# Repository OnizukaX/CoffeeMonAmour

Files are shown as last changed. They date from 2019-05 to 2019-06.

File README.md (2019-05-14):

# CoffeeMonAmour

For aficionados sharing coffee machines e.g. in a company using RFID authentication badges.

A good office day usually starts with a cup of your favorite beverage. You go to the nearest coffee machine, select your favorite beverage and look at it slowly filling up your favorite mug. Then, possibly, you will start looking for your name on a sheet of paper and put a tick under it, you will later have to pay your dues. Then as the day goes, you run from one meeting to another one, and frequently stop by other coffee machines ran by other coffee aficionados. The process repeats itself again and again.
Keeping finances up to date slowly becomes complicated and unpaid paper sheets soon become your new paperwall.

Without any hardware modification, you can add extra devices that track user accross all the coffee machines.

## DataFlow
NodeMCU + RFID reader + MIFARE Classic card --(WiFi)--> Google Script --> Google Spreadsheet --> Google Script --(WiFi)--> NodeMCU

## Hardware
* 1x NodeMCU ESP-WROOM-32 [https://cdn.shopify.com/s/files/1/1509/1638/files/ESP_-_32_NodeMCU_Developmentboard_Datenblatt_a3bf98d8-6a53-4d26-8f1c-c61b1c82af39.pdf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, https://www.espressif.com/sites/default/files/documentation/esp32-wroom-32_datasheet_en.pdf]
* 1x RFID-RC522 [
https://cdn.shopify.com/s/files/1/1509/1638/files/RFID_RC522_Set_mit_Reader_Chip_und_Card_13_56MHz_Datenblatt.pdf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, https://www.nxp.com/docs/en/data-sheet/MFRC522.pdf]
* 1x MIFARE Classic card [https://www.nxp.com/docs/en/data-sheet/MF1S50YYX_V1.pdf]
* 3x LEDs (red, green and blue)
* 1x OLED display with SSD1306 driver (e.g. GM009605)
* 1x micro-USB cable (check your wires if you get a Brown Out Reset (BOR))
* 1x screw for the capacitive touch button (combined with a ESP32 capacity touch pad)

## Libraries
* SPI [ESP32]
* WiFiClientSecure [ESP32]
* MFRC522 [https://github.com/miguelbalboa/rfid]
* SSD1306 [https://github.com/ThingPulse/esp8266-oled-ssd1306]

## Credits for pulling things together
* "ESP32 and RFID-RC522 module example" [http://www.esp32learning.com/code/esp32-and-rfid-rc522-module-example.php]
* "ESP32 und Google Tabellen (Sheets)" [http://esp32-server.de/google-sheets/]

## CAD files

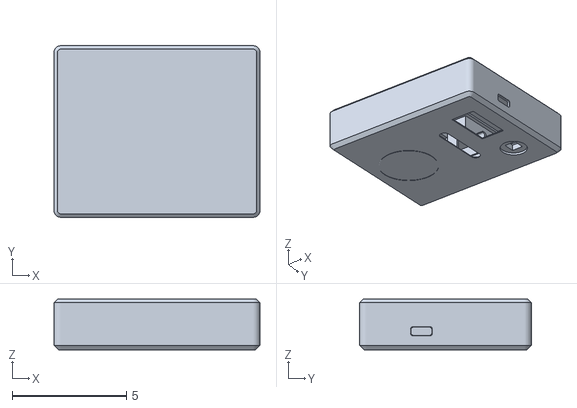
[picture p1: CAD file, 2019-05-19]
CoffeeMonAmour_Case_Group.stl
9.00 x 7.50 x 2.22

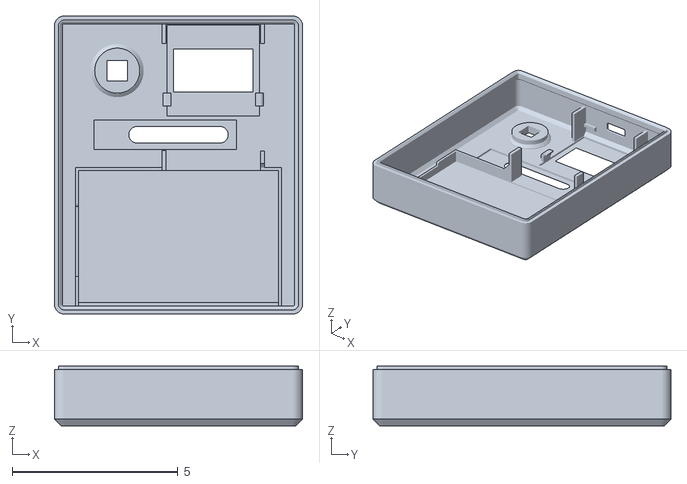
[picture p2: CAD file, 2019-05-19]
CoffeeMonAmour_Case_Top.stl
7.50 x 9.00 x 1.80

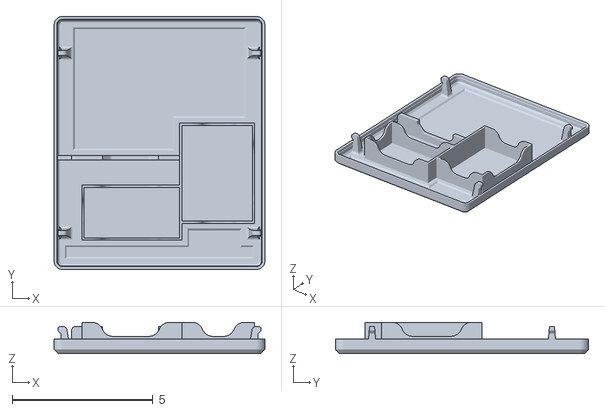
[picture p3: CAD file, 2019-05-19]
CoffeeMonAmour_Case_Bottom.stl
7.50 x 9.00 x 1.12

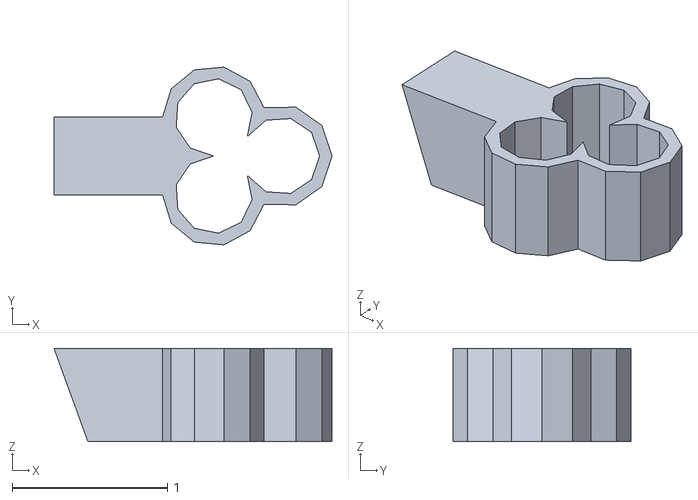
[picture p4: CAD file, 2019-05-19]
CoffeeMonAmour_Case_Led_Holder.stl
1.79 x 1.15 x 0.6

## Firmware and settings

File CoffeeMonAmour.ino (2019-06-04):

#include "Remote.hpp"
#include "Reader.hpp"
#include "Hmi.hpp"

/*
  Default pins layout.
  +---------+-------+------+-----+--------+
  | NodeMCU | RC522 | OLED | LED | Button |
  +---------+-------+------+-----+--------|
  | GPIO-21 |  SDA  |      |     |        |
  | GPIO-18 |  SCK  |      |     |        |
  | GPIO-23 |  MOSI |      |     |        |
  | GPIO-19 |  MISO |      |     |        |
  | GPIO-22 |  RST  |      |     |        |
  | GPIO-5  |       | SCK  |     |        |
  | GPIO-4  |       | SDA  |     |        |
  | GPIO-33 |       |      |  R  |        |
  | GPIO-26 |       |      |  G  |        |
  | GPIO-25 |       |      |  B  |        |
  | GPIO-27 |       |      |     |  Touch |
  +---------+-------+------+-----+--------+
  The RC522 and the OLED display are powered with 3.3V.
  The LEDs@20Ma are powered with 3.3V and each of them is in series with a 100Ohm resistors.
*/

/* Determine on which Core Arduino is running. */
#if CONFIG_FREERTOS_UNICORE
# define ARDUINO_RUNNING_CORE 0
#else
# define ARDUINO_RUNNING_CORE 1
#endif

#define GOOGLE_KEY "XXX"

#define DATA_SUCCESS_BLINK_NB (3U)
#define DATA_SUCCESS_BLINK_PERIOD_MS (600U)
#define DATA_ERROR_DISPLAY_MS (2000U)

/* Print debug data. */
#define DEBUG_ON (false)

#define DEFAULT_SSID "XXX"
#define DEFAULT_PASSWORD "XXX"

/* Remote configuration. */
Remote::RemoteConfig remoteCfg = {
  .ssid       = DEFAULT_SSID,
  .password   = DEFAULT_PASSWORD,
  .serverRootUrl  = "script.google.com",
  .serverScriptUrl = String("https://script.google.com/macros/s/") + GOOGLE_KEY + String("/exec?")
};

/* Reader configuration. */
Reader::ReaderConfig readerCfg = {
  .chipSelectPin      = 21,
  .resetPowerDownPin  = 22,
  .readPeriod_ms      = 2000
};

/* Hmi configuration. */
Hmi::HmiConfig hmiCfg = {
  .address           = 0x3C,
  .sdaPin            = 4,
  .sdcPin            = 5,
  .touchButtonPin    = T7,
  .touchButtonThresh = 30, /* Thresh=30 took empirically. */
  .wifiStatusPin     = 25,
  .dataStatusPin     = 26,
  .errorStatusPin    = 33
};

/* State-machine. */
enum StateMachine
{
  NONE = 0,
  INIT_START,
  INIT_FINISHED,
  WAITING_FOR_CARD,
  TICKING_COFFEE,
  BALANCE_ENQUIRED,
  BALANCE_RETRIEVAL,
  ENQUIRING_BALANCE,
  DATA_SUCCESS,
  DATA_FAILURE,
  CONNECTION_FAILURE
};

struct GlobalParams
{
  StateMachine state;
  unsigned long enquiryTimeLeft_ms;
  String scriptResponse;
  bool displayPreemption;
};

GlobalParams gParams = {
  .state = StateMachine::NONE,
  .enquiryTimeLeft_ms = 0,
  .scriptResponse = "",
  .displayPreemption = false
};

/* Remote server to communicate with. */
Remote remote(remoteCfg, &log);
/* RFID Card reader. */
Reader reader(readerCfg, &log);
/* Hmi. */
Hmi hmi(hmiCfg);

void setup()
{
  /* Init. serial at 115200 bps. */
  Serial.begin(115200);
  while (!Serial);

  /* Handling Hmi on Arduino Core. Arduino sketch runs on Core1 by default.
    note: Core1 seems to be the best for Serial I/O.
    https://docs.espressif.com/projects/esp-idf/en/latest/api-reference/system/freertos.html */
  xTaskCreatePinnedToCore(hmiWrapper, "hmiWrapper", 10000, NULL, 1, NULL, ARDUINO_RUNNING_CORE);

  /*
  * Workers setup.
  */
  /* HMI */
  hmi.setup();
  gParams.state = INIT_START;
  String displayLogs("HMI setup...");
  hmi.writeSmall(displayLogs += "ok\n");
  /* Reader */
  hmi.writeSmall(displayLogs += "RFID reader setup...");
  reader.setup();
  hmi.writeSmall(displayLogs += "ok\n");
  /* Remote */
  hmi.writeSmall(displayLogs += "Connecting to WiFi...");
  bool initRemote = remote.setup();
  hmi.writeSmall(displayLogs += (initRemote) ? "ok" : "error");
  gParams.state = INIT_FINISHED;
  hmi.clear();

  log("[SETUP] done");
}

void loop()
{
  if (remote.isConnected())
  {
    if (gParams.displayPreemption)
    {
      /* Do nothing: HMI has the upper hand. */
    }
    else
    {
      if (reader.readUID()) /* Card read. */
      {
        String urlParameters = String("CoffeeMachineID=1&EmployeeCardID=") + reader.getUID();
        if (hmi.isBalanceEnquiryActive(gParams.enquiryTimeLeft_ms))
        {
          gParams.state = BALANCE_RETRIEVAL;
          urlParameters += "&Balance=1";
        }
        else
        {
          gParams.state = TICKING_COFFEE;
        }

        const String url = remote.getScriptUrl() + urlParameters;
        
        if (remote.sendData(url, gParams.scriptResponse))
        {
          if (TICKING_COFFEE == gParams.state)
          {
            /* Overwritting the server reply. */
            gParams.scriptResponse = "OK";
          }

          gParams.state = DATA_SUCCESS;
          gParams.displayPreemption = true;
          log("[DATA] data transmitted: " + gParams.scriptResponse);
        }
        else
        {
          gParams.state = DATA_FAILURE;
          gParams.displayPreemption = true;
          log("[DATA] error: " + gParams.scriptResponse);
        }
      }
      else
      {
        /* Button status. */
        if (hmi.isButtonPressed())
        {
          hmi.setBalanceEnquiry(millis());
          gParams.state = BALANCE_ENQUIRED;
        }
        else if (hmi.isBalanceEnquiryActive(gParams.enquiryTimeLeft_ms))
        {
          gParams.state = BALANCE_ENQUIRED;
        }
        else
        {
          hmi.setBalanceEnquiry(0);
          /* No new card detected. */
          gParams.state = WAITING_FOR_CARD;
        }
      }
    }
  }
  else
  {
    /* Error: not connected to remote. */
    gParams.state = CONNECTION_FAILURE;
  }
}

/* Print out debug info. */
void log(const String& msg)
{
  if (DEBUG_ON)
  {
    Serial.println(msg);
  }
  else
  {
    /* Do nothing. */
  }
}

/* Handle delegated HMI task. */
void hmiWrapper(void* pvParameters)
{
  static unsigned long timer_ms = 0;

  while (true)
  {
    /* Required to avoid Task Watchdog Timer (TWDT) being triggered when loop executes nothing (not yielding).
      note: disableCoreXWDT() seems not to be a good solution for this. */
    delay(10);

    if ((gParams.displayPreemption) && (timer_ms == 0))
    {
      timer_ms = millis();
    }

    switch (gParams.state)
    {
      case NONE:
        /* Do nothing: HMI not even initialized. */
        break;
      case INIT_START: /* Setup method called, HMI must first be initialized. */
        hmi.setWDEStatusLights(true, true, true);
        break;
      case INIT_FINISHED: /* Setup method finished. */
        hmi.setWDEStatusLights(false, false, false);
        break;
      case WAITING_FOR_CARD:
        /* Blinking to know if the µC is still running. */
        hmi.setWDEStatusLights((millis() % 1000) > 500, false, false);
        hmi.writeBig("Swipe card");
        break;
      case TICKING_COFFEE: /* Sending data to remote. */
        hmi.setWDEStatusLights(false, true, false);
        hmi.fillCoffeeCup();
        break;
      case BALANCE_ENQUIRED: /* Button pressed. */
        hmi.clear();
        hmi.writeSmall("Balance enquiry...", false);
        hmi.drawProgressBar((gParams.enquiryTimeLeft_ms * 100) / hmi.getEnquiryTimeout());
        hmi.display();
        break;
      case BALANCE_RETRIEVAL: /* Request being processed. */
        hmi.setWDEStatusLights(false, true, false);
        hmi.clear();
        hmi.writeSmall("Retrieving balance...", false);
        static const uint16_t speed = 8 * 1000;
        hmi.drawProgressBar((100 * (speed - (millis() % speed))) / speed);
        hmi.display();
        break;
      case DATA_SUCCESS: /* Data successfully transmitted. */
        if ((millis() - timer_ms) <= (DATA_SUCCESS_BLINK_NB * DATA_SUCCESS_BLINK_PERIOD_MS))
        {
          hmi.writeBig(gParams.scriptResponse);
          /* Makes the LED blink to show that data have been transmitted. */
          hmi.setWDEStatusLights(false, ((millis() - timer_ms) / (DATA_SUCCESS_BLINK_PERIOD_MS >> 2)) % 2, false);
        }
        else
        {
          timer_ms = 0;
          gParams.displayPreemption = false;
          gParams.state = WAITING_FOR_CARD;
        }
        break;
      case DATA_FAILURE:
        if ((millis() - timer_ms) <= DATA_ERROR_DISPLAY_MS)
        {
          hmi.setWDEStatusLights(false, false, true);
          hmi.writeBig("Error!");
        }
        else
        {
          timer_ms = 0;
          gParams.displayPreemption = false;
          gParams.state = WAITING_FOR_CARD;
        }
        break;
      case CONNECTION_FAILURE: /* Could either not connect to W-LAN or no internet connection. */
        hmi.setWDEStatusLights(false, false, true);
        hmi.writeBig("WiFi issue!");
        break;
      default:
        /* Unexpected -> error. */
        hmi.setWDEStatusLights(false, false, true);
        hmi.writeBig("???");
        break;
    }
  }
}

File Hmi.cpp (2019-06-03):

#include <Wire.h>
#include <SSD1306Wire.h>

#include "Hmi.hpp"

Hmi::Hmi(const HmiConfig& cfg) :
  m_display(SSD1306Wire(cfg.address, cfg.sdaPin, cfg.sdcPin)),
  m_wifiStatusPin(cfg.wifiStatusPin),
  m_dataStatusPin(cfg.dataStatusPin),
  m_errorStatusPin(cfg.errorStatusPin),
  m_touchButtonPin(cfg.touchButtonPin),
  m_touchButtonThresh(cfg.touchButtonThresh),
  m_balanceEnquiry_ms(0),
  m_enquiryTimeout_ms(5000) {}

void Hmi::setup()
{
  m_display.init();
  m_display.clear();
  m_display.display();
  //m_display.flipScreenVertically();

  /* LEDs pins setup. */
  pinMode(m_wifiStatusPin, OUTPUT);
  pinMode(m_dataStatusPin, OUTPUT);
  pinMode(m_errorStatusPin, OUTPUT);
}

void Hmi::write(const String& f_text, const bool f_clearNdisplay, const int16_t f_x, const int16_t f_y, const uint8_t& f_fontData)
{
  if (f_clearNdisplay) m_display.clear();
  m_display.setFont(&f_fontData);
  m_display.drawString(f_x, f_y, f_text);
  if (f_clearNdisplay) m_display.display();
}

bool Hmi::isButtonPressed() const
{
  /* Debounce noise measurements. */
  const uint8_t NB_MEAS = 3;
  uint32_t sumValues = 0;
  for (uint8_t i = 0; i < NB_MEAS; ++i)
  {
    sumValues += touchRead(m_touchButtonPin);
  }
  return (static_cast<uint16_t>(sumValues / NB_MEAS) <= m_touchButtonThresh);
}

bool Hmi::isBalanceEnquiryActive(unsigned long& f_timeLeft_ms) const
{
  f_timeLeft_ms = constrain((0 == m_balanceEnquiry_ms) ? 0 : static_cast<long long>(m_enquiryTimeout_ms - abs(millis() - m_balanceEnquiry_ms)),
                            0,
                            m_enquiryTimeout_ms);
  return (0 != m_balanceEnquiry_ms) && (abs(millis() - m_balanceEnquiry_ms) < m_enquiryTimeout_ms);
}

void Hmi::drawProgressBar(uint8_t f_progress, uint8_t f_margin_x, uint8_t f_margin_y)
{
  m_display.drawProgressBar(f_margin_x,
                            f_margin_y,
                            m_display.getWidth() - (2 * f_margin_x),
                            m_display.getHeight() - (2 * f_margin_y),
                            f_progress);
}

void Hmi::fillCoffeeCup()
{
  static const int16_t cupWidth = 30;
  static const int16_t cupHeight = 40;
  static const int16_t x0 = (m_display.getWidth() / 2) - (cupWidth / 2);
  static const int16_t y0 = (m_display.getHeight() - cupHeight) / 2;
  static const int16_t handleRadius = 5;
  static const int16_t pouringSpeed = 8 * 1000;

  m_display.clear();

  /* Cup. */
  m_display.fillRect(x0, y0, cupWidth, cupHeight);
  /* Handle. */
  m_display.drawCircleQuads(x0 + cupWidth - 1, y0 + cupHeight / 2, handleRadius, 0b00001001);
  m_display.drawCircleQuads(x0 + cupWidth - 1, y0 + cupHeight / 2, handleRadius + 1, 0b00001001);
  /* Filled coffee. */
  m_display.setColor(BLACK);
  m_display.fillRect(x0 + 2, y0, cupWidth - 4, (cupHeight * (pouringSpeed - (millis() % pouringSpeed))) / pouringSpeed);
  m_display.setColor(WHITE);
  /* Pouring coffee. */
  m_display.drawVerticalLine(x0 + (cupWidth / 2), y0 - 10, cupHeight + 10);
  /* Saucer. */
  m_display.drawHorizontalLine(x0 - 10, y0 + cupHeight + 1, cupWidth + (2 * 10));

  m_display.display();
}

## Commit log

2019-05-02 Added basic debug output via GPIO (WiFi, Data, Error).
    [CoffeeMonAmour.ino]
2019-05-14 Added OLED driver specification. Added USB caveat.
2019-05-14 Added capacity touch pad / button sensing.
2019-05-14 Only lighting up Data when reading a card. Turning on Error when not connected to WiFi.
    [CoffeeMonAmour.ino]
2019-05-14 Delegated LEDs handling to Hmi.
2019-05-15 Pipelined setup text. Switching on all LEDs during the setup, then off after the initialization.
2019-05-15 Added balance enquiry via touch button.
2019-05-19 Added STL files of Case
    [CoffeeMonAmour_Case_Bottom.stl, CoffeeMonAmour_Case_Group.stl, CoffeeMonAmour_Case_Led_Holder.stl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]
2019-05-19 Corrected pin layout comment. Not switching all LEDs off at each loop cycle.
    [CoffeeMonAmour.ino]
2019-06-04 Fixed raced condition for HMI display. Got rid of delay method calls.
    [CoffeeMonAmour.ino]
